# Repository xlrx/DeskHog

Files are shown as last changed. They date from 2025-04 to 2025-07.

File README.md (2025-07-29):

# DeskHog: A developer toy for sparking developer joy

Screenshot 2025-04-18 at 1 31 29 AM

## Dive in

Ready to put your kit together? [Start here.](/getting-started/start-here.md)

## What is DeskHog?
DeskHog is an open-source, 3D printed, palm-sized developer toy. 

It's a toy to tinker with, adapt, and to get curious with. We'll be folding in a library of simple example games and apps, including a pomodoro timer and versions of Pong, Rogue, Flappy Bird. You can see PRs for these in this repo now for inspiration!

We think that sounds like fun and, if you do too, then DeskHog is for you. 

## OK, but what is it?

DeskHog packs an Adafruit ESP32-S3 Reverse TFT Feather in a custom-made 3D printed case. It comes complete with a 240x135 color TFT display, a 10-hour battery life, WiFi, and a cute little LED so you can find it in the dark.

A [plug-and-play DeskHog hardware kit](https://posthog.com/merch) is coming soon (so you can get everything in one box). In the meantime, here’s what you’ll need if you want to make DeskHog yourself right now. 

- ESP32-S3 Reverse TFT Feather – [`Adafruit 5691`](https://learn.adafruit.com/esp32-s3-reverse-tft-feather) – buy: [Adafruit](https://www.adafruit.com/product/5691), [DigiKey](https://www.digikey.com/en/products/detail/adafruit-industries-llc/5691/18627502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), [Mouser](https://www.mouser.com/ProductDetail/Adafruit/5691?qs=mELouGlnn3eeALy2e3r3sw%3D%3D), [Botland (EU)](https://botland.store/arduino-compatible-boards-adafruit/22891-feather-esp32-s3-reverse-with-tft-display-wifi-module-4mb-flash-2mb-psram-compatible-with-arduino-adaf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), [The Pi Hut (UK)](https://thepihut.com/products/adafruit-esp32-s3-reverse-tft-feather-4mb-flash-2mb-psram-stemma-qt), [Electromaker](https://www.electromaker.io/shop/product/adafruit-esp32-s3-reverse-tft-feather-4mb-flash-2mb-psram-stemma-qt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), [BerryBase (EU)](https://www.berrybase.de/en/adafruit-esp32-s3-reverse-tft-feather)
- Optional: PKCell 552035 350mAh 3.7V LiPoly battery – buy: [Adafruit](https://www.adafruit.com/product/2750), [Tinytronics (EU)](https://www.tinytronics.nl/en/power/batteries/li-po/pkcell-li-po-battery-3.7v-350mah-jst-ph-lp552035), [BerryBase (EU)](https://www.berrybase.de/en/lp-552035-lithium-polymer-lipo-akku-3-7v-350mah-mit-2-pin-jst-stecker)
- 3D printed enclosure – print: [3mf file](3d-printing)

## What can DeskHog do?

DeskHog can do a couple of things by default, but the real joy lies in expanding the capabilities by adding them yourself. 

### Out of the box functionality

A couple of basic [cards](#card-stack) (screens) are included on the firmware and were built by [Danilo Campos](https://posthog.com/community/profiles/31731).

- **ProvisioningCard**: Displays a QR code to connect to the device and shows connection stats.
- **InsightCard**: Visualizes PostHog data. Still a bit of a WIP, so contributions welcome!
- **FriendCard**: Lets Max the hedgehog visit with you and provide encouragement.

### Available games and apps

We're working on adding some of the following games to an `/examples` folder which will include a selection of games and apps for you to play with. If you can't see them in the `/examples` folder it's probably because they exist as [unapproved PRs](https://github.com/PostHog/DeskHog/pulls) while we work on them. No problem, just checkout the branch!

Example games include:

- **Pog**: A Pong clone by [Leon Daly](https://posthog.com/community/profiles/30833)
- **IdleHog**: An idle clicker by [Chris McNeill](https://posthog.com/community/profiles/33534)
- **One Button Dungeon**: An idle Roguelike by [Joe Martin](https://posthog.com/community/profiles/29070)
- **Dictator or Techbro: DeskHog Edition**: A quiz game by [Chris McNeill](https://posthog.com/community/profiles/33534)
- **Notchagotchi**: A virtual pet by [Sophie Payne](https://posthog.com/community/profiles/33385)
- **Flappy Hog**: A Flappy Bird clone by [Joe Martin](https://posthog.com/community/profiles/29070)
- **Hog Speed**: A reaction game by [Chris McNeill](https://posthog.com/community/profiles/33534)
- **Pineapple Reflex**: A pizza-based game by [Sophie Payne](https://posthog.com/community/profiles/33385)
- **Three Button Dungeon**: An Ultima-like by [Joe Martin](https://posthog.com/community/profiles/29070)

Example apps include:

- **Awkwardness Avoider**: A smalltalk prompter by [Annika Schmid](https://posthog.com/community/profiles/28619)
- **Pomodoro**: A productivity timer by [Annika Schmid](https://posthog.com/community/profiles/28619)

All of the example apps were built in 24 hours at [a PostHog hackathon](https://posthog.com/handbook/company/offsites) by people who hadn't coded before at all. These example cards are a testament to [what's possible when vibe coding on DeskHog](#-vibe-coding-with-ai-agents), but some lack polish - so make sure you know [how to reset DeskHog](#buttons-and-reset-sequences). Just in case.

## Developing for DeskHog

Review [tech-details.md](tech-details.md) for info on architecture, libraries and key components used in this project.

## Troubleshooting

### No matter what I do, flashing the board doesn't change anything! wtf??

We're actually cutting the storage space in half so that over the air updates can be loaded to the unused half of storage. You can end up in a place where the board just won't boot to the correct partition.

To fix this, choose **Erase Flash and Upload** from the PlatformIO Project Tasks menu.

## 🤖 Coding with AI Agents

> DeskHog is optimized for agent development. If you've never tried coding with AI before, here's [a guide to get you started](https://posthog.com/tutorials/deskhog-claude-tutorial)!

We couldn't have built DeskHog without the help of agent development workflows, and we encourage agent-driven development with a few caveats.

LLMs often struggle with multi-threaded embedded systems. DeskHog’s firmware has strict rules for core/task roles; AI might overlook them unless you guide it.

If you're looking to [get started](https://posthog.com/tutorials/deskhog-claude-tutorial), we recommend using [Claude Code](https://www.anthropic.com/claude-code) with [Visual Studio Code](https://code.visualstudio.com/) and the [PlatformIO extension](https://platformio.org/install/ide?install=vscode). They work well together and you can build all sorts of things with natural language.

Use `tech-details.md` to give your agent broad context on the device. Still, even with that you should bear in mind the following advice:

- You should encourage AI to follow existing patterns: use`EventQueue` for cross-core messaging and update the UI only on the UI task.
- Flag any AI suggestions that touch the UI from the wrong core.
- Review and test thoroughly—watch for “LLM slop” (unused vars, odd delays) and clean it up.

Think of your AI as a speedy junior dev: brilliant but prone to mistakes. You’re the senior dev keeping it on track. With that balance, AI can boost productivity while keeping DeskHog reliable.

## Power off

If you want to turn the device off, hold ● + ▼ for two seconds. The device will enter deep sleep mode. 

To wake the device, press the reset tab on the left. 

## UI progress
- Status card: working
- WiFi provisioning card with QR Code: working
- Friend card to give you (mild) reassurance: working
- Numeric card for Big Number insights: working
- Funnel card: needs a redesign; probably should be horizontal layout instead, won't display more than three steps right now
- Line graph card: broken, not properly scaling larger data sets, probably fine if you have an insight scoped between 7-30 days
- Other insights: not yet supported

## Request for PRs

The following PRs would be interesting, and may earn you a free DeskHog kit or other merch:

- Additional insight parsing and visualizations for Insight Card
- More games and apps! We think limiting things to one available button prompts creativity
- Support for other boards and displays
- LLM slop mitigation: if you see anything obviously stupid in this code that hasn't yet been caught and cleaned up
- DX improvements around task isolation: if your experience with embedded code says there's a better way to architect this, happy to follow your lead
- Improved C++: not my preferred language, feel free to suggest idiomatic and architectural improvements
- Desk utilities, like a pomodoro timer; also constrained: center button only. Be creative!
- PlatformIO config improvements: flashing builds causes a reboot that seems unnecessary, maybe you know a better configuration

## Forks

This firmware has a simple goal: make it easy to set up a stack of screens that you can page through easily, managed by a web UI. But this is just one way to use the power of the board we chose. Feel free to steal this code, keep what helps, throw out what you don't like, and try something totally different. If you get somewhere interesting with your fork, let us know with a pull request to edit this section!

## Feedback

PRs over issues, but if you've got any trouble, feel free to open an issue. You can also contact the maintainer, danilo@posthog.com.

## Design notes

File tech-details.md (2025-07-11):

# DeskHog technical details

Microcontrollers are a pain. They've got limited memory and, for our purposes here, you've got to write C++ 🫠

But in exchange, our code can touch reality like no other kind of project. Here's what we're dealing with.

### Core and task isolation

If you've ever written mobile code, you'll feel right at home: we can only update the UI via the UI thread, otherwise the board crashes.

We've got two cores and multiple "tasks" assigned between them – task is [FreeRTOS](https://github.com/espressif/arduino-esp32/tree/master/libraries/ESP32/examples/FreeRTOS/BasicMultiThreading)-speak for threads:

**Core 0 (Protocol CPU) tasks:**

- WiFi
- Web portal server
- Insight parsing
- NeoPixel control

**Core 1 (Application CPU) tasks:**

- LVGL tick (maintains timing, animations, etc for the graphics library) 
- UI: screen drawing and input handling

We have to keep this stuff carefully isolated or we're going to crash.

### Buttons

diagram

If the board isn't responding:

- Hold **▼ (Page down/D0)**
- Press **Reset**
- Release **▼ (Page down/D0)**

The board will restart in bootloader mode, where it can be re-flashed using PlatformIO.

### Pin definitions

You don't have to guess the pin definitions. You'll find them documented here:

~/.platformio/packages/framework-arduinoespressif32/variants/adafruit_feather_esp32s3_reversetft/pins_arduino.h

## UI progress

- Status card: working
- WiFi provisioning card with QR Code: working
- Friend card to give you (mild) reassurance: working
- Numeric card for Big Number insights: working
- Funnel card: needs a redesign; probably should be horizontal layout instead, won't display more than three steps right now
- Line graph card: working decently, but could use more detail
- Other insights: not yet supported

## Important components

### Event queue

`EventQueue` is how the project manages communication between tasks and prevents coupling. Events – changes via the web UI, returned requests from the PostHog client – are dispatched out of core 0 to be received by the UI task. Any important data can be safely copied from one context into the other, preventing crashes and other drama.

### Card stack

The UI is a stack of cards. The user navigates between them using built-in buttons (the arrow keys)

`CardNavigationStack` manages the UI presentation of these cards, animating transitions.

`CardController` manages updates to the stack contents. If an insight is deleted or added via web UI, the controller processes that update reactively.

### Web UI

A basic provisioning and configuration UI is provided. You can access it via a QR code on first launch, and by the IP shown in the status screen once WiFi is configured.

Open `html/portal.html` in your browser to preview changes. The contents of `html` are inlined into a single file on each build by `htmlconvert.py`.

**Web portal budget:** Right now the portal costs about 18KB. We'll allow up to **100KB**. All portal assets must be locally available, since the portal needs to work when the device doesn't have WiFi. If you want to try adding a more complex UI framework than hand-rolled JS and HTML, you're welcome to try as long as its build system is quick and the final static output is under 100KB.

### Card system

The DeskHog uses a dynamic card system that allows users to configure which cards appear on their device through a web UI. Cards are managed by the `CardController` and can be easily extended by developers.

#### Built-in cards

`ProvisioningCard` displays a QR code to connect to the device. If WiFi is connected, it displays connection stats.

`InsightCard` visualizes PostHog data. Numeric card is working best. The rest need help.

`FriendCard` lets Max the hedgehog visit with you and provide encouragement.

#### Adding new card types

To create a new card type, you need to:

1. **Add to CardType enum** - Add your new type to the `CardType` enum in `src/ui/CardController.h`
2. **Create the card class** - Implement your card UI using LVGL
3. **Register the card type** - Add it to CardController's registration system
4. **Add configuration support** (optional) - If your card needs user input

**Example: Adding a simple "Hello World" card**

```cpp
// 1. Add to CardType enum (src/ui/CardController.h)
enum class CardType {
    INSIGHT = 0,
    FRIEND = 1,
    HELLO = 2  // Add your new type here
};

// 2. Create your card class (src/ui/HelloCard.h)
class HelloCard {
public:
    HelloCard(lv_obj_t* parent);
    lv_obj_t* getCard() const { return _card; }

private:
    lv_obj_t* _card;
};

// 3. Register in CardController::initializeCardTypes()
CardDefinition helloDef;
helloDef.type = CardType::HELLO;
helloDef.name = "Hello world";
helloDef.allowMultiple = true;
helloDef.needsConfigInput = false;
helloDef.uiDescription = "A simple greeting card";
helloDef.factory = [this](const String& configValue) -> lv_obj_t* {
    HelloCard* newCard = new HelloCard(screen);
    return newCard ? newCard->getCard() : nullptr;
};
registerCardType(helloDef);
```

**Card definition properties:**
- `type`: Unique enum value for your card type
- `name`: Display name in the web UI
- `allowMultiple`: Whether users can add multiple instances
- `needsConfigInput`: Whether the card requires configuration input
- `configInputLabel`: Label for the config input field (if needed)
- `uiDescription`: Description shown in the web UI
- `factory`: Lambda function that creates card instances

#### Web UI integration

The web UI automatically displays available card types with:
- Add buttons for cards that can be added
- Configuration inputs for cards that need them
- Status indicators showing how many instances are configured
- Drag-and-drop reordering for configured cards

No web UI changes are needed when adding new card types - everything is driven by the card registration system.

#### Creating game-like cards

Cards that need regular updates (games, animations, real-time visualizations) can use the `InputHandler::update()` method:

```cpp
// 1. Your card class should inherit from InputHandler
class FlappyHogCard : public InputHandler {
public:
    // Handle button presses (required by InputHandler)
    bool handleButtonPress(uint8_t button_index) override {
        // Return false to allow navigation, true if you handled it
        return false;
    }
    
    // Update method for game logic (called ~60 times per second)
    bool update() override {
        if (game) {
            game->loop();  // Update game state
            return true;   // Continue receiving updates
        }
        return false;      // Stop updates
    }
    
    // Required for proper cleanup
    void prepareForRemoval() override {
        // Called before LVGL object deletion
    }
};

// 2. Register the card with an InputHandler
helloDef.factory = [this](const String& configValue) -> lv_obj_t* {
    FlappyHogCard* newCard = new FlappyHogCard(screen);
    if (newCard && newCard->getCard()) {
        // Register as InputHandler to receive updates
        cardStack->registerInputHandler(newCard->getCard(), newCard);
        return newCard->getCard();
    }
    delete newCard;
    return nullptr;
};
```

The `update()` method is automatically called by the UI system when your card is active/visible. This approach:
- Works within the existing task/core architecture
- Doesn't require creating new tasks or timers
- Automatically stops updates when the card isn't visible
- Maintains proper thread safety through the existing UI queue system

### Insight parser and PostHog client

`InsightParser` ingests PostHog API responses and makes them available to the UI. `PostHogClient` constructs requests and dispatches responses.

### LVGL

This project relies on the powerful [LVGL project](https://docs.lvgl.io/9.2/intro/index.html) at [v9.2.2](https://registry.platformio.org/libraries/lvgl/lvgl?version=9.2.2) for drawing, animation and other UI tasks.

### Config manager and captive portal

`ConfigManager` handles persistent storage and retrieval of credentials and insights. `CaptivePortal` provides the web server and interacts with `ConfigManager` to read and write to persistent storage.

### PNG sprite system

The project includes a `png2c.py` script that automatically converts PNG images into LVGL-compatible C arrays. This makes it easy to add sprite-based animations and graphics to DeskHog. The script runs before each build, so your sprites are always up to date. Beware: the board has limited storage and we already use most of it. Optimize your images aggressively and use PNG files sparingly.

#### How it works

1. **Place PNG files in subdirectories** under `raw-png/`:
   ```
   raw-png/
   ├── walking/
   │   ├── frame_01.png
   │   ├── frame_02.png
   │   └── frame_03.png
   ├── idle/
   │   ├── idle_01.png
   │   └── idle_02.png
   └── attack/
       └── attack_01.png
   ```

2. **Run the conversion script**:
   ```bash
   python3 png2c.py
   ```

3. **Generated output**:
   - Individual header/source files for each sprite in `include/sprites/`
   - Filenames are preserved (e.g., `frame_01.png` → `sprite_frame_01.h/c`)
   - A master `sprites.h` and `sprites.c` containing arrays for each subdirectory

#### Using sprites in your code

```cpp
#include "sprites/sprites.h"

// Access the walking animation array
lv_obj_t* img = lv_img_create(parent);
lv_img_set_src(img, &walking_sprites[0]);  // First frame

// Animate through frames
for (int i = 0; i < walking_sprites_count; i++) {
    lv_img_set_src(img, walking_sprites[i]);
    // Add delay or use LVGL animation
}
```

#### Features

- **Automatic grouping**: Each subdirectory gets its own array (e.g., `walking_sprites[]`, `idle_sprites[]`)
- **Count variables**: Each array has a corresponding count (e.g., `walking_sprites_count`)
- **LVGL compatible**: Generates ARGB8888 format data structures that work directly with LVGL 9.x

#### Requirements

- Python 3
- Pillow and numpy (required):
  ```bash
  pip install Pillow numpy
  ```

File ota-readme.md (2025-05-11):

# DeskHog OTA Updates via GitHub Releases

This document outlines the plan for implementing Over-the-Air (OTA) firmware updates for the DeskHog project using GitHub Releases as the firmware source and integrating the process into the existing web configuration portal.

## Core Requirements for ESP32 OTA

Implementing OTA updates on the ESP32 with the Arduino framework requires several key components:

1.  **Partition Scheme:** The ESP32's flash memory needs an OTA-compatible partition table defined in `partitions.csv`. This typically includes at least two application partitions (e.g., `factory`, `ota_0`) and an `otadata` partition to manage which partition boots.
2.  **Network Connectivity:** The device must connect to Wi-Fi to check for and download updates.
3.  **Update Source:** A server to host the firmware binary (`.bin`). We will use GitHub Releases for this.
4.  **Arduino `Update` Library:** The `Update.h` library provided by the ESP32 Arduino core is used to write the downloaded firmware to the inactive partition and manage the boot process.
5.  **Update Logic:** Application code is needed to check for updates, download the binary, feed it to the `Update` library, handle errors, provide feedback, and trigger a reboot.
6.  **Firmware Binary:** The compiled `.bin` file generated by PlatformIO.
7.  **Security (Recommended):** Using HTTPS for downloads prevents tampering. Certificate management is required. Firmware signing is another potential enhancement.
8.  **Rollback:** The ESP32 bootloader provides basic rollback if a new firmware fails to boot successfully multiple times.

## Update Source: GitHub Releases Method

We will use the GitHub Releases feature of the project repository to host firmware updates:

1.  **Release Assets:** New firmware builds (`.bin` files) will be uploaded as assets to tagged releases (e.g., `v1.1.0`) on GitHub.
2.  **Checking for Updates:**
    *   The ESP32 will make an HTTPS GET request to the GitHub API endpoint: `https://api.github.com/repos/PostHog/DeskHog/releases/latest`.
    *   Requires an HTTPS client on the ESP32 and the necessary root CA certificate for `api.github.com`.
3.  **Parsing Response:**
    *   The JSON response from the API will be parsed (using `ArduinoJson`).
    *   Extract `tag_name` (version) and the `browser_download_url` for the `.bin` asset.
4.  **Version Comparison:** Compare the `tag_name` from GitHub with the currently running firmware version.
5.  **Downloading Binary:** If a newer version is found, make an HTTPS GET request to the `browser_download_url`.
6.  **Applying Update:** Stream the downloaded binary data to the Arduino `Update` library (`Update.writeStream()`). Call `Update.end()` and `ESP.restart()` on success.

## Web UI Integration (`portal.html` / `portal.js`)

The existing captive portal UI will be extended to manage OTA updates:

1.  **`portal.html` Changes:**
    *   Add a new "Firmware Update" section.
    *   Display "Current Version" (`<span id="current-version">`).
    *   Display "Available Version" (`<span id="available-version">`).
    *   Add a "Check for Updates" button (`<button id="check-update-btn">`).
    *   Add an initially hidden "Install Update" button (`<button id="install-update-btn">`).
    *   Add an optional area to display release notes (`<pre id="release-notes">`).
    *   Add a status display area for ongoing updates, including a progress bar (`<div id="update-status-container">`, `<div id="update-progress-bar">`).
    *   Add an area for displaying update errors (`<p id="update-error-message">`).

2.  **`portal.js` Changes:**
    *   **`checkFirmwareUpdate()`:** Called on page load and by the "Check" button. Fetches `/check-update`, updates the UI with current/available versions, and shows the "Install" button if an update is available.
    *   **`startFirmwareUpdate()`:** Called by the "Install" button. Confirms with the user, then POSTs to `/start-update`. On success, it initiates status polling.
    *   **`pollUpdateStatus()`:** (Optional but recommended) Called periodically after an update starts. Fetches `/update-status`, updates the progress bar and status message, and stops polling on success or error. Handles completion or errors.
    *   Modify `DOMContentLoaded` listener to call `checkFirmwareUpdate()` on initial page load.

## Backend Implementation (`CaptivePortal` / `OtaManager`)

The backend logic will reside primarily in a new class, coordinated by the existing `CaptivePortal`.

1.  **`OtaManager` (New Class):**
    *   **Responsibilities:**
        *   Encapsulate all core OTA logic.
        *   Store GitHub repository details and current firmware version.
        *   Manage HTTPS connections (including certificates) to `api.github.com`.
        *   Perform API calls (`/releases/latest`).
        *   Parse JSON responses.
        *   Download the `.bin` file via HTTPS using `WiFiClientSecure`.
        *   Interact with the Arduino `Update` library (`Update.begin`, `Update.writeStream`, `Update.end`).
        *   Track update state (idle, checking, downloading, writing, success, error) and progress.
        *   Trigger `ESP.restart()`.
    *   **Interface (Conceptual):**
        *   `struct UpdateInfo { bool updateAvailable; String currentVersion; String availableVersion; String downloadUrl; String releaseNotes; };`
        *   `UpdateInfo checkForUpdate();`
        *   `bool beginUpdate(String downloadUrl);`
        *   `struct UpdateStatus { String status; int progress; String message; };`
        *   `UpdateStatus getStatus();` // For polling

2.  **`CaptivePortal` Modifications:**
    *   **Dependencies:** Add a reference to an `OtaManager` instance (passed via constructor).
    *   **New Handler Methods:**
        *   `handleCheckUpdate()`: Calls `otaManager.checkForUpdate()`, formats the `UpdateInfo` struct into a JSON response for the UI.
        *   `handleStartUpdate()`: Retrieves the download URL (likely cached from the last check or passed from the UI), calls `otaManager.beginUpdate()`, responds with success/failure JSON.
        *   `handleUpdateStatus()`: Calls `otaManager.getStatus()`, formats the `UpdateStatus` struct into a JSON response.
    *   **`CaptivePortal::begin()`:** Register routes `/check-update` (GET), `/start-update` (POST), and `/update-status` (GET) to map to the new handler methods.

## Implementation Progress

*   **Partition Scheme (`partitions.csv`):** Updated to support OTA with two application partitions (~1.84MB each) and a smaller SPIFFS partition (256KB).
    *   _Affected file:_ `partitions.csv`
*   **`OtaManager` Class (`src/OtaManager.h`, `src/OtaManager.cpp`):
    *   Skeleton created with basic structure, structs (`UpdateInfo`, `UpdateStatus`), and method signatures.
    *   `_githubApiRootCa` updated with DigiCert Global Root G2 certificate.
    *   `checkForUpdate()` method implemented as **non-blocking** using a FreeRTOS task (`_checkUpdateTaskRunner`):
        *   Handles HTTPS GET request to GitHub API (`_performHttpsRequest`).
        *   Parses JSON response (`_parseGithubApiResponse`).
        *   Compares versions and identifies firmware asset URL.
        *   Updates internal status and makes results available via `getStatus()` and `getLastCheckResult()`.
    *   _Affected files:_ `src/OtaManager.h`, `src/OtaManager.cpp`

## Next Steps (OtaManager)

1.  Implement `OtaManager::beginUpdate()` using a FreeRTOS task to handle firmware download (HTTPS) and flashing with `Update.writeStream()`.
2.  Implement robust error handling and status reporting for the `beginUpdate` process.
3.  Implement a reliable mechanism for defining/retrieving `CURRENT_FIRMWARE_VERSION`.

This structure maintains separation of concerns, keeping web request handling (`CaptivePortal`) distinct from the OTA update mechanism (`OtaManager`).

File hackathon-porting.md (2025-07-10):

# Hackathon Card Porting Guide

This document outlines the process for porting old hackathon branches to the new card architecture in DeskHog.

## Overview

The main branch introduced a new extensible card system that allows dynamic card management through a web UI. Old branches need to be updated to use this architecture.

## Step-by-Step Porting Process

### 1. Understand the New Architecture

The new system uses:
- **CardType enum** - Defines available card types
- **CardDefinition** - Metadata for each card type
- **Factory pattern** - Lambda functions create card instances
- **InputHandler interface** - Base class for cards that handle input
- **Dynamic card management** - Cards can be added/removed via web UI

### 2. Analyze the Existing Implementation

For the Flappy Hog example:
- Original: `FlappyBirdGame` class with direct integration in main.cpp
- Had custom button handling and game loop in the LVGL task
- Direct references in CardController

### 3. Create a Card Wrapper Class

Create a wrapper that implements `InputHandler`:

```cpp
class FlappyHogCard : public InputHandler {
public:
    FlappyHogCard(lv_obj_t* parent);
    ~FlappyHogCard();
    
    lv_obj_t* getCard();
    bool handleButtonPress(uint8_t button_index) override;
    void prepareForRemoval() override;
    bool update() override;  // For game loop
    
private:
    FlappyBirdGame* game;
    lv_obj_t* cardContainer;
    bool markedForRemoval;
};
```

### 4. Update CardType Enum

In `src/config/CardConfig.h`:
- Add new card type to enum
- Update `cardTypeToString()` function
- Update `stringToCardType()` function

### 5. Register the Card Type

In `CardController::initializeCardTypes()`:
```cpp
CardDefinition flappyDef;
flappyDef.type = CardType::FLAPPY_HOG;
flappyDef.name = "Flappy Hog";
flappyDef.allowMultiple = false;
flappyDef.needsConfigInput = false;
flappyDef.uiDescription = "One button. Endless frustration. Infinite glory.";
flappyDef.factory = [this](const String& configValue) -> lv_obj_t* {
    FlappyHogCard* newCard = new FlappyHogCard(screen);
    if (newCard && newCard->getCard()) {
        CardInstance instance{newCard, newCard->getCard()};
        dynamicCards[CardType::FLAPPY_HOG].push_back(instance);
        cardStack->registerInputHandler(newCard->getCard(), newCard);
        return newCard->getCard();
    }
    delete newCard;
    return nullptr;
};
registerCardType(flappyDef);
```

### 6. Handle Game Updates

For cards needing regular updates:
1. Extend `InputHandler` interface with `virtual bool update() { return false; }`
2. Add `updateActiveCard()` to `CardNavigationStack`
3. Call it from `CardController::processUIQueue()`

This keeps the game loop encapsulated and running at the same frequency as UI updates.

### 7. Remove Old Integration Code

Clean up:
- Direct references in main.cpp
- Card-specific methods in CardController
- Manual card creation in initialization

### 8. Test the Integration

Verify:
- Card appears in web UI
- Can be added/removed dynamically
- Game functions properly
- No memory leaks or crashes
- Proper cleanup on removal

## Common Pitfalls

1. **Threading issues** - Keep all UI updates on the LVGL thread
2. **Memory management** - Use `prepareForRemoval()` to prevent double-deletion
3. **Button handling** - Return false from `handleButtonPress()` to allow navigation
4. **Update frequency** - Game updates run at UI refresh rate (~60 FPS)

## Benefits of the New System

- **Extensible** - Easy to add new card types
- **Dynamic** - Users control which cards are shown
- **Encapsulated** - No card-specific code in core systems
- **Consistent** - All cards follow the same pattern
- **Thread-safe** - Updates happen through the UI queue

## Merge Strategy

1. Commit your changes on the feature branch
2. Merge main into your branch (expect conflicts)
3. Resolve conflicts keeping the new architecture
4. Test thoroughly before creating PR

The key is to wrap the existing functionality in the new card system rather than trying to preserve the old integration approach. Do not accept changes that alter the architecture of the project as a whole.

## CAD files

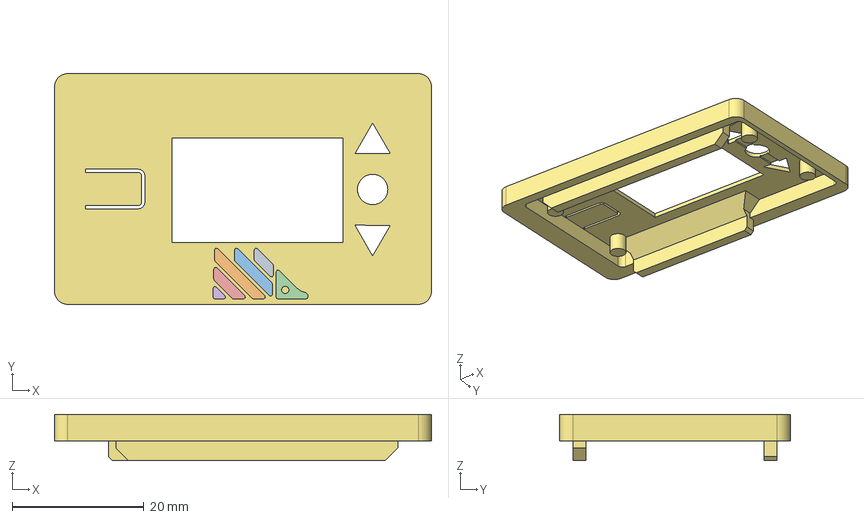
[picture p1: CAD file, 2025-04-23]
3d-printing/cad/Bezel assembly.step
57.2 x 35.0 x 7.00 mm

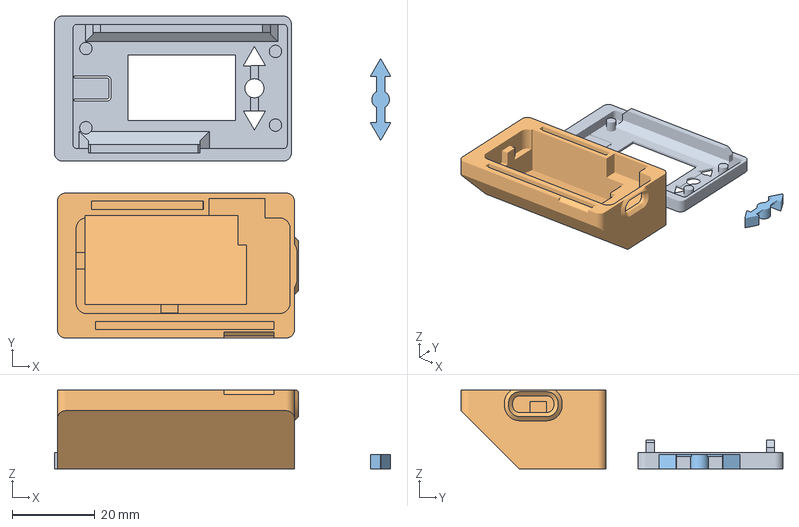
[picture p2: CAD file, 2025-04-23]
3d-printing/DeskHog-all_parts.3mf
81.1 x 77.7 x 19.0 mm
Bezel assembly
Enclosure*
Keypad

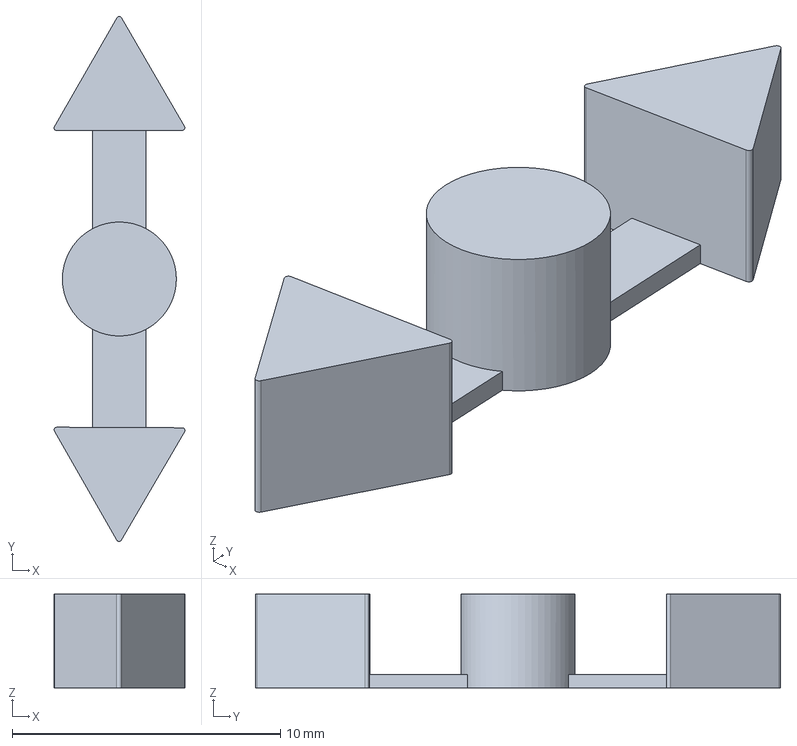
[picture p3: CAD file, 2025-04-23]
3d-printing/cad/Keypad.step
4.88 x 19.6 x 3.50 mm

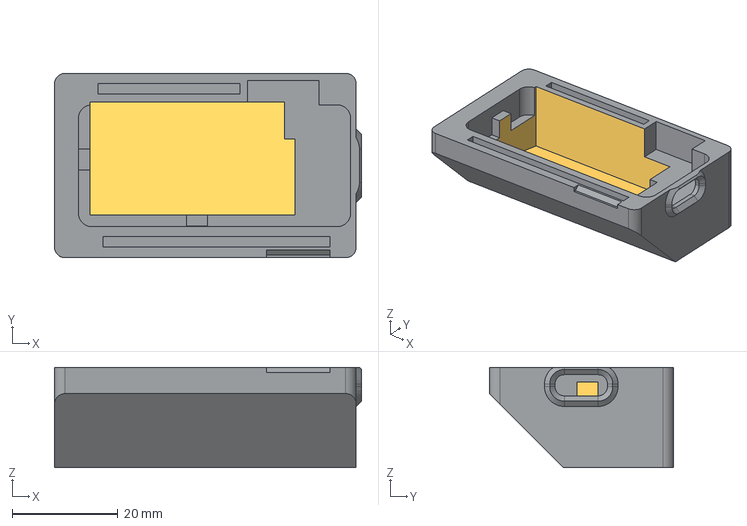
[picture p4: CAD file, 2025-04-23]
3d-printing/cad/Enclosure.step
58.2 x 35.0 x 19.0 mm

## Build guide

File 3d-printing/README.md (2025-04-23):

# Printing

`DeskHog-all_parts.3mf` contains everything you need to print your own DeskHog. All parts are at their intended printing orientations.

DeskHog prints have been tested with PETG on Bambu printers. For best results, stick with translucent PETG. The tool-free, friction-fit assembly requires dialed-in dimensional accuracy (Bambu worked fine out of the box, others may require some tuning). If the pieces are a little snug, a modeling file or sandpaper across the tabs on the bezel can probably get you on your way.

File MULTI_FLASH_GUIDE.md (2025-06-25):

# Multi-Board Flash Utility for DeskHog

This utility automatically detects and flashes DeskHog firmware to multiple ESP32-S3 boards as they are connected.

## Features

- Automatically detects new ESP32-S3 Feather boards when plugged in
- Maintains an in-memory list of already-flashed boards to prevent re-flashing
- Supports parallel flashing of multiple boards
- Real-time monitoring of board connections/disconnections
- Live progress display with visual progress bars
- Status tracking for each board (building, flashing, verifying, etc.)
- Verbose mode for debugging

## Requirements

- Python 3.6+
- PlatformIO CLI (`pip install platformio`)
- pyserial (`pip install pyserial`)
- USB drivers for ESP32-S3

## Usage

### Basic Usage

From the DeskHog project root directory:

```bash
python multi_flash.py
```

Or if you made it executable:

```bash
./multi_flash.py
```

### Command Line Options

- `-v, --verbose`: Show detailed flashing output
- `-f, --firmware <path>`: Use a specific firmware file instead of building
- `-r, --reset`: Clear the list of flashed boards and exit

### Examples

1. **Basic monitoring and flashing:**
   ```bash
   python multi_flash.py
   ```

2. **Verbose mode (see detailed upload progress):**
   ```bash
   python multi_flash.py -v
   ```

3. **Flash a specific firmware file:**
   ```bash
   python multi_flash.py -f .pio/build/adafruit_feather_esp32s3_reversetft/firmware.bin
   ```

4. **Reset the flashed board memory:**
   ```bash
   python multi_flash.py -r
   ```

## How It Works

1. The script continuously scans for connected USB devices
2. When it detects an ESP32-S3 board (by VID/PID or description), it checks if it's already been flashed
3. New boards are automatically flashed using PlatformIO's upload command
4. Successfully flashed boards are remembered to prevent re-flashing
5. The script handles multiple boards simultaneously using threading
6. A real-time display shows:
   - Active flashing operations with progress bars
   - Current status (building, connecting, writing, verifying)
   - Completed boards with success/failure indicators
   - Total count of flashed boards

## Board Detection

The script identifies ESP32-S3 boards by:
- USB Vendor ID: 0x303A (Espressif) or 0x239A (Adafruit)
- USB Product ID: Various ESP32-S3 identifiers
- Device description containing "ESP32", "ESP32-S3", "Adafruit", or "Feather"

## Troubleshooting

### Board not detected
- Make sure the board is in normal mode (not bootloader mode)
- Check USB cable and connection
- Try verbose mode to see what devices are being detected

### Flashing fails
- The board might need to be put in bootloader mode manually (hold D0 while pressing Reset)
- Check that PlatformIO is properly installed
- Ensure you're running from the DeskHog project root directory

### Board keeps getting re-flashed
- This might happen if the board doesn't have a unique serial number
- Try disconnecting and reconnecting the board
- Use the reset option (`-r`) to clear the memory if needed

## Tips

- Keep the script running while connecting multiple boards
- Boards can be connected one at a time or multiple at once
- The display automatically refreshes to show real-time progress
- Progress bars show the current stage of flashing (0-100%)
- Status indicators:
  - 🔄 = Currently flashing
  - ✅ = Successfully flashed
  - ❌ = Failed to flash
  - ⚠️  = Disconnected during flash
- Press Ctrl+C to stop monitoring

## Display Example

```
================================================================================
DeskHog Multi-Board Flash Monitor
================================================================================
Time: 14:32:15 | Press Ctrl+C to stop
--------------------------------------------------------------------------------

📊 Board Status (2 flashed, 1 active):

  🔄 /dev/cu.usbmodem14201 [████████████████░░░░░░░░░░░░░] 54% - Writing firmware
  ✅ 303A:1001:ABCD1234                                     - ✓ Successfully flashed
  ✅ 239A:811C:XYZ789                                       - ✓ Successfully flashed

--------------------------------------------------------------------------------
💡 Tip: Boards are automatically detected and flashed when plugged in
```

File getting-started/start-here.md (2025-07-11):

Welcome to the adventure of programmable hardware.

Let’s get you going.

# What's going on?

DeskHog is a palm-sized computer that connects to WiFi. What happens after that is something you can decide by writing new code for it. We've done our best to take care of the boring stuff for you:

- WiFi setup
- Drawing to the screen
- Building an interface so you can navigate between different cards
- A web portal to change settings

From here you can make simple games, connect to web services, or come up with your own adventure.

# Assembly

Whether you received DeskHog as a kit or printed a case yourself, assembly is pretty straightforward. The battery wire will take a moment of finesse.

You’re going to make a sandwich, in this order:

- Base (largest plastic piece)
- Battery
- Board
- Buttons
- Top face (with the PostHog logo)

Stack those pieces together and you’re done.

## Finessing the battery

The battery cable can be a little annoying. Here are tips:

Your battery includes a small piece of tape. Reuse that tape to *bind the battery wires together*. It works best to place the tape at the midpoint of the wires.

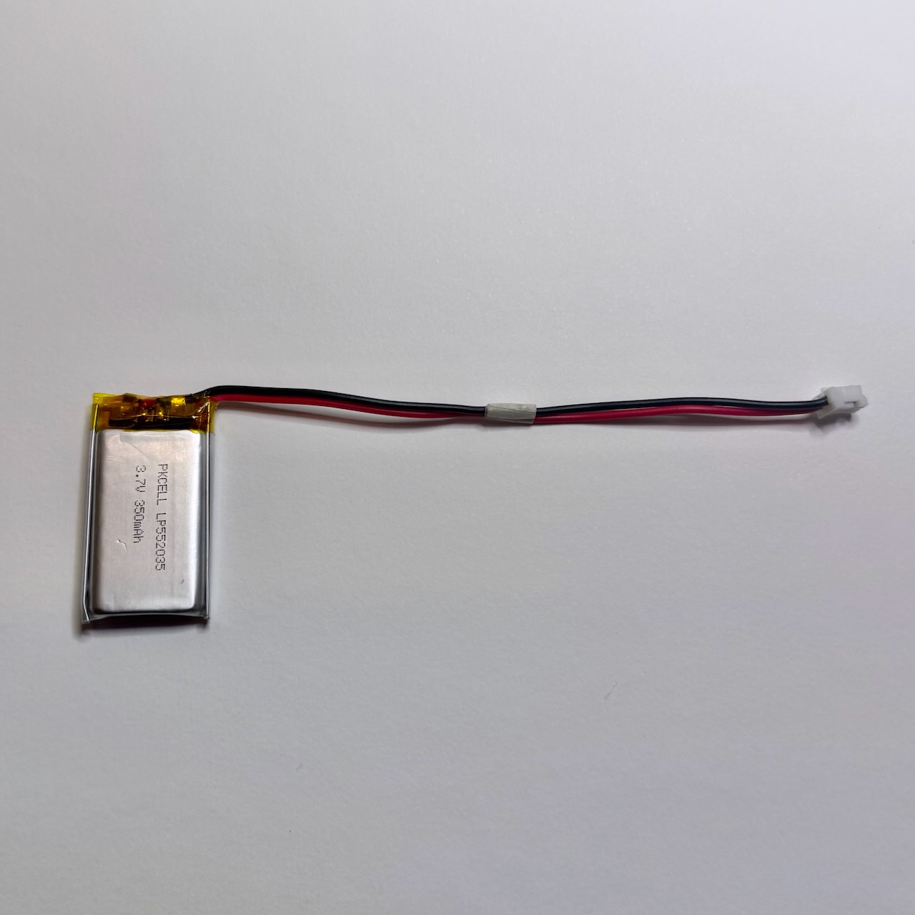
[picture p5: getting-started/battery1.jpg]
Battery wire taping


Once secured, gently but firmly bend the wires to form a **V** right before the tape, on the side of the battery.

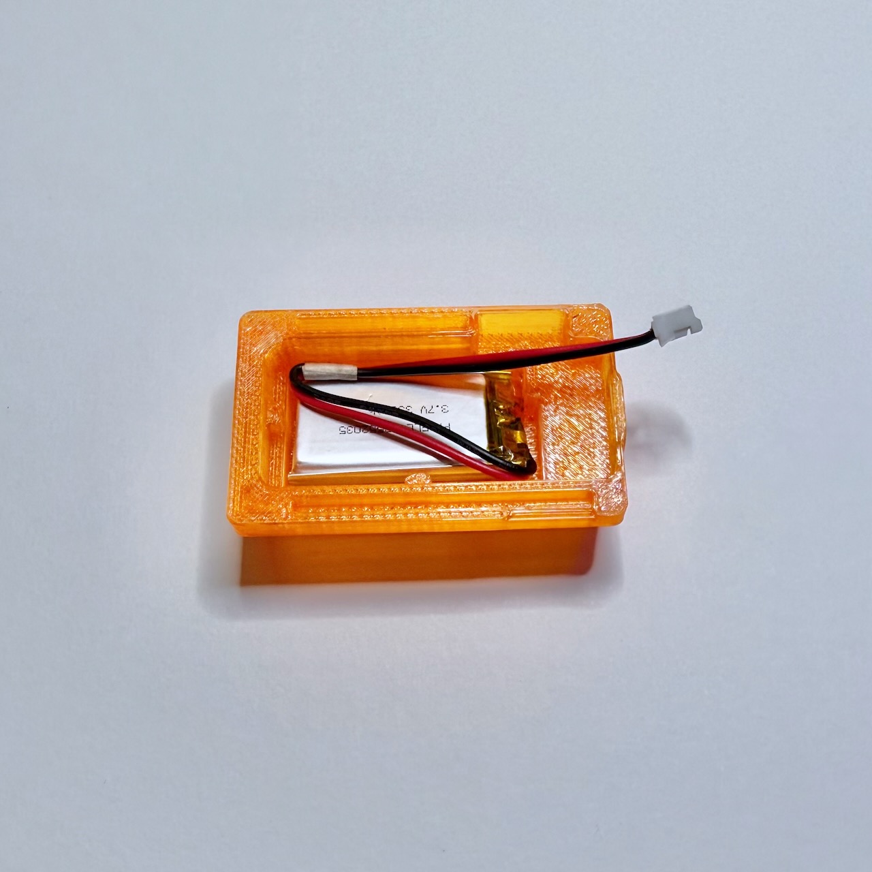
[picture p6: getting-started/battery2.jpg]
Battery wire bending


Align the spot on the battery where the wires come out with the small notch cut into the battery well.

From here, attach the battery to the board and attempt to lay the board into its space.

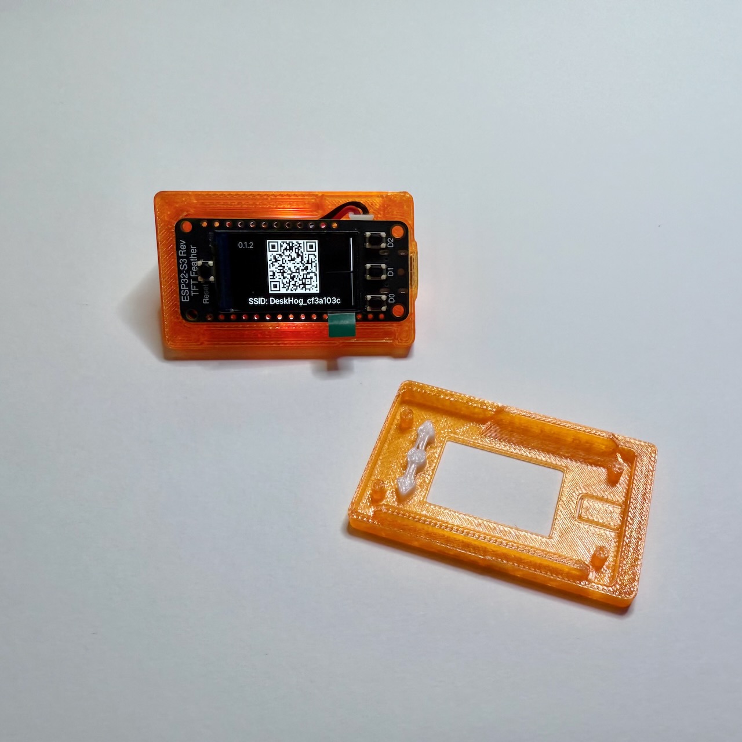
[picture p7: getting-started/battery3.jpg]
Battery placement


# Dive in

Once assembled, you can scan DeskHog’s QR code to access its configuration portal. You can also connect directly from any computer by choosing the WiFi SSID shown under the QR code from your machine’s WiFi menu.

After you give DeskHog WiFi credentials, you can access the portal again anytime by visiting its IP in your web browser. DeskHog’s status card, always shown at the top of the stack, will show its IP. You should also update to the latest firmware via the portal.

The project includes a `Hello, world!` card in `src/ui/examples`. You can start noodling with it immediately. To add or remove the card, visit DeskHog’s configuration portal.

Ready to go deeper? Check out [this tutorial](https://posthog.com/tutorials/deskhog-claude-tutorial) on how you can use agent coding products like Claude to build more interesting things on DeskHog's software. Whether you're a robot or a human, the [tech-details.md](/tech-details.md) file will help you get your bearings.

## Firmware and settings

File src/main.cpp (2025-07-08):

/**
 * DeskHog - PostHog Analytics Display
 * ===================================
 * 
 * An ESP32-S3-based project that displays PostHog analytics insights on a 240x135 TFT screen.
 * Built for the Adafruit ESP32-S3 Reverse TFT Feather, this project provides a compact, desk-friendly way to monitor your PostHog analytics in real-time.
 * 
 * Components:
 * - Hardware: ESP32-S3 with integrated 240x135 TFT display
 * - UI: LVGL-based card interface for displaying insights
 * - Network: WiFi connectivity with captive portal for configuration
 * 
 * Development note:
 * Keep this main.cpp file lean, tidy and simple. Do not leak implementation details into the main file.
 * Keep main.cpp focused on setup and task creation. Encapsulate and isolate components into their own files.
 */

#include <Arduino.h>
#include <lvgl.h>
#include <Adafruit_ST7789.h>
#include "ConfigManager.h"
#include "hardware/WifiInterface.h"
#include "hardware/NeoPixelController.h"
#include "ui/CaptivePortal.h"
#include "ui/ProvisioningCard.h"
#include "hardware/DisplayInterface.h"
#include "ui/CardNavigationStack.h"
#include "ui/InsightCard.h"
#include "hardware/Input.h"
#include "posthog/PostHogClient.h"
#include "Style.h"
#include "esp_heap_caps.h" // For PSRAM management
#include "ui/CardController.h"
#include "EventQueue.h"
#include "esp_partition.h" // Include for partition functions
#include "OtaManager.h"
#include <esp_sleep.h> // Added for deep sleep functionality
#include <esp_pm.h> // Added for power management

// Display dimensions
#define SCREEN_WIDTH 240
#define SCREEN_HEIGHT 135

// LVGL display buffer size
#define LVGL_BUFFER_ROWS 135  // Full screen height

// Button configuration
#define NUM_BUTTONS 3
const uint8_t BUTTON_PINS[NUM_BUTTONS] = {
    Input::BUTTON_DOWN,    // BOOT button
    Input::BUTTON_CENTER,  // Center button
    Input::BUTTON_UP       // Up button
};

// Define the global buttons array
Bounce2::Button buttons[NUM_BUTTONS];

// Global objects
DisplayInterface* displayInterface;
ConfigManager* configManager;
WiFiInterface* wifiInterface;
CaptivePortal* captivePortal;
CardController* cardController; // Replace individual card objects with controller
PostHogClient* posthogClient;
EventQueue* eventQueue; // Add global EventQueue
NeoPixelController* neoPixelController;  // Renamed from neoPixelManager
OtaManager* otaManager;

// Task handles
TaskHandle_t wifiTask;
TaskHandle_t portalTask;
TaskHandle_t insightTask;
TaskHandle_t neoPixelTask;

// WiFi connection timeout in milliseconds
#define WIFI_TIMEOUT 30000

// WiFi task that handles WiFi operations
void wifiTaskFunction(void* parameter) {
    while (1) {
        // Process WiFi events
        wifiInterface->process();
        
        // Delay to prevent hogging CPU
        vTaskDelay(pdMS_TO_TICKS(10));
    }
}

// Captive portal task that handles web server requests
void portalTaskFunction(void* parameter) {
    while (1) {
        captivePortal->processAsyncOperations(); // Process pending portal actions
        // Delay to prevent hogging CPU
        vTaskDelay(pdMS_TO_TICKS(100)); // Check for operations every 100ms
    }
}

// Insight processing task
void insightTaskFunction(void* parameter) {
    while (1) {
        posthogClient->process();  // Use the global instance
        vTaskDelay(pdMS_TO_TICKS(100));  // Check every 100ms
    }
}

// LVGL handler task that includes button polling - added here to consolidate UI operations
void lvglHandlerTask(void* parameter) {
    TickType_t lastButtonCheck = xTaskGetTickCount();
    const TickType_t buttonCheckInterval = pdMS_TO_TICKS(50); // Check buttons every 50ms
    
    static unsigned long powerOffPressStartTime = 0;
    // static bool upPressedState = false; // Unused
    // static bool downPressedState = false; // Unused

    while (1) {
        // Handle LVGL tasks
        displayInterface->handleLVGLTasks();

        cardController->processUIQueue();
        
        // Poll buttons at regular intervals
        TickType_t currentTime = xTaskGetTickCount();
        if ((currentTime - lastButtonCheck) >= buttonCheckInterval) {
            lastButtonCheck = currentTime;
            
            // Update all buttons first
            for (int i = 0; i < NUM_BUTTONS; i++) {
                buttons[i].update();
            }

            // Get current state of UP and DOWN buttons
            // BUTTON_UP is pressed when HIGH (INPUT_PULLDOWN)
            // BUTTON_DOWN is pressed when LOW (INPUT_PULLUP)
            bool centerButtonHeld = (buttons[Input::BUTTON_CENTER].read() == HIGH);
            bool downButtonHeld = (buttons[Input::BUTTON_DOWN].read() == LOW);

            if (centerButtonHeld && downButtonHeld) {
                if (powerOffPressStartTime == 0) { // Both pressed, start timer
                    powerOffPressStartTime = millis();
                } else {
                    if (millis() - powerOffPressStartTime >= 2000) { // Held for 2 seconds
                        Serial.println("Simultaneous CENTER and DOWN hold for 2s detected. Entering deep sleep.");
                        // Optional: Turn off display backlight or other peripherals before sleep
                        // displayInterface->setBacklight(0); // Example if such a function exists
                        esp_deep_sleep_start();
                    }
                }
            } else {
                // If either button is released or not simultaneously pressed, reset the timer
                powerOffPressStartTime = 0;

                // Process individual button presses if power-off sequence is not active or completed.
                // Check .pressed() for single press actions (triggers on state change).
                // This ensures that navigation still works if the power-off combo isn't fully executed.
                if (buttons[Input::BUTTON_UP].pressed()) {
                    // Ensure this doesn't trigger if it was part of the combo that just got released
                    // However, .pressed() fires on the transition, so if it was held and released, 
                    // it won't fire again here unless pressed again separately.
                    cardController->getCardStack()->handleButtonPress(Input::BUTTON_UP);
                }
                if (buttons[Input::BUTTON_DOWN].pressed()) {
                    cardController->getCardStack()->handleButtonPress(Input::BUTTON_DOWN);
                }
                if (buttons[Input::BUTTON_CENTER].pressed()) {
                    cardController->getCardStack()->handleButtonPress(Input::BUTTON_CENTER);
                }
            }
        }
        
        vTaskDelay(pdMS_TO_TICKS(5));
    }
}

// NeoPixel update task
void neoPixelTaskFunction(void* parameter) {
    while (1) {
        neoPixelController->update();
        vTaskDelay(pdMS_TO_TICKS(5));  // Small delay to prevent task starvation
    }
}

void setup() {
    Serial.begin(115200); // Keep Serial.begin() as it initializes the port
    delay(100);  // Give serial port time to initialize
    Serial.println("Starting up...");

    if (psramInit()) {
        Serial.println("PSRAM initialized successfully");
        Serial.printf("Total PSRAM: %d bytes\n", ESP.getPsramSize());
        Serial.printf("Free PSRAM: %d bytes\n", ESP.getFreePsram());
        
        // Set memory allocation preference to PSRAM
        heap_caps_malloc_extmem_enable(4096);
    } else {
        Serial.println("PSRAM initialization failed!");
        while(1); // Stop here if PSRAM init fails
    }

    // Configure power management for automatic light sleep
    esp_pm_config_t pm_config = {
        .max_freq_mhz = 240,  // Maximum CPU frequency
        .min_freq_mhz = 10,   // Minimum CPU frequency when idle
        .light_sleep_enable = true  // Enable automatic light sleep
    };
    
    esp_err_t pm_result = esp_pm_configure(&pm_config);
    if (pm_result == ESP_OK) {
        Serial.println("Power management configured: Light sleep enabled");
    } else {
        Serial.printf("Failed to configure power management: %s\n", esp_err_to_name(pm_result));
    }
    
    // Add Partition Logging Here
    Serial.println("--- Partition Table Info ---");
    esp_partition_iterator_t it = esp_partition_find(ESP_PARTITION_TYPE_ANY, ESP_PARTITION_SUBTYPE_ANY, NULL);
    if (it == NULL) {
        Serial.println("Could not find partitions!");
    } else {
        while (it != NULL) {
            const esp_partition_t *p = esp_partition_get(it);
            if (p == NULL) {
                // Added null check for safety, might occur if iterator is exhausted
                it = esp_partition_next(it); // Make sure to advance iterator even if partition is null
                continue;
            }
            Serial.printf("  Label: %-10s Type: 0x%02x Subtype: 0x%02x Offset: 0x%08x Size: 0x%08x (%d KB)\n",
                          p->label, p->type, p->subtype, p->address, p->size, p->size / 1024);
            it = esp_partition_next(it);
        }
        esp_partition_iterator_release(it); // Release the iterator!
    }
    Serial.println("--------------------------");

    // UI queue will be initialized by CardController


    SystemController::begin();
    
    // Initialize styles and fonts
    Style::init();
    
    // Initialize event queue first
    eventQueue = new EventQueue(20); // Create queue with capacity for 20 events
    eventQueue->begin(); // Start event processing
    
    // Initialize NeoPixel controller
    neoPixelController = new NeoPixelController();
    neoPixelController->begin();
    
    // Initialize config manager with event queue
    configManager = new ConfigManager(*eventQueue);
    configManager->begin();
    
    // Initialize PostHog client with event queue
    posthogClient = new PostHogClient(*configManager, *eventQueue);
    
    // Initialize display manager
    displayInterface = new DisplayInterface(
        SCREEN_WIDTH, SCREEN_HEIGHT, LVGL_BUFFER_ROWS, 
        TFT_CS, TFT_DC, TFT_RST, TFT_BACKLITE
    );
    displayInterface->begin();
    
    // Initialize WiFi manager with event queue
    wifiInterface = new WiFiInterface(*configManager, *eventQueue);
    wifiInterface->begin();
    
    // Initialize buttons
    Input::configureButtons();
    
    // Configure GPIO wakeup for buttons to wake from light sleep
    gpio_wakeup_enable((gpio_num_t)Input::BUTTON_UP, GPIO_INTR_HIGH_LEVEL);
    gpio_wakeup_enable((gpio_num_t)Input::BUTTON_DOWN, GPIO_INTR_LOW_LEVEL);  
    gpio_wakeup_enable((gpio_num_t)Input::BUTTON_CENTER, GPIO_INTR_HIGH_LEVEL);
    esp_sleep_enable_gpio_wakeup();
    Serial.println("GPIO wakeup configured for buttons");
    
    // Create and initialize card controller
    cardController = new CardController(
        lv_scr_act(),
        SCREEN_WIDTH,
        SCREEN_HEIGHT,
        *configManager,
        *wifiInterface,
        *posthogClient,
        *eventQueue
    );
    
    // Initialize with display interface directly
    cardController->initialize(displayInterface);
    
    // Initialize OtaManager
    otaManager = new OtaManager(CURRENT_FIRMWARE_VERSION, "PostHog", "DeskHog");
    
    // Initialize captive portal
    captivePortal = new CaptivePortal(*configManager, *wifiInterface, *eventQueue, *otaManager, *cardController);
    captivePortal->begin();
    
    // Create task for WiFi operations
    xTaskCreatePinnedToCore(
        wifiTaskFunction,
        "wifiTask",
        4096,
        NULL,
        1,
        &wifiTask,
        0
    );
    
    // Create task for captive portal
    xTaskCreatePinnedToCore(
        portalTaskFunction,
        "portalTask",
        8192,
        NULL,
        1,
        &portalTask,
        1
    );
    
    // Create task for insight processing
    xTaskCreatePinnedToCore(
        insightTaskFunction,
        "insightTask",
        8192,
        NULL,
        1,
        &insightTask,
        0
    );
    
    // Create LVGL tick task
    xTaskCreatePinnedToCore(
        DisplayInterface::tickTask,
        "lv_tick_task",
        2048,
        NULL,
        1,
        NULL,
        1
    );
    
    // Create LVGL handler task (now includes button polling)
    xTaskCreatePinnedToCore(
        lvglHandlerTask,
        "lvglTask",
        8192,
        NULL,
        2,
        NULL,
        1
    );
    
    // Create NeoPixel task
    xTaskCreatePinnedToCore(
        neoPixelTaskFunction,
        "neoPixelTask",
        2048,
        NULL,
        1,
        &neoPixelTask,
        0
    );
    
    // Check if we have WiFi credentials and publish the appropriate event
    configManager->checkWiFiCredentialsAndPublish();

    SystemController::setSystemState(SystemState::SYS_READY);
}

void loop() {
    // Empty - tasks handle everything
    vTaskDelete(NULL);
    
}

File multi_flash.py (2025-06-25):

#!/usr/bin/env python3
"""
Multi-board flash utility for DeskHog
Automatically detects and flashes new ESP32-S3 boards when connected
"""

import serial.tools.list_ports
import subprocess
import time
import sys
import threading
import os
from datetime import datetime
from typing import Set, Dict, Optional
import argparse
import re
from collections import defaultdict

class BoardFlasher:
    def __init__(self, firmware_path: Optional[str] = None, verbose: bool = False):
        self.flashed_boards: Set[str] = set()
        self.running = True
        self.verbose = verbose
        self.firmware_path = firmware_path
        self.lock = threading.Lock()
        
        # Board status tracking
        self.board_status = {}  # board_id -> status string
        self.board_progress = {}  # board_id -> progress percentage
        self.active_flashing = {}  # board_id -> port device
        self.status_lock = threading.Lock()
        
        # ESP32-S3 vendor/product IDs
        self.target_vids = [0x303A]  # Espressif
        self.target_pids = [0x1001]  # ESP32-S3 USB JTAG/serial
        
        # Adafruit Feather ESP32-S3 can also appear as
        self.alt_vids = [0x239A]  # Adafruit
        self.alt_pids = [0x811C, 0x811D]  # Various Adafruit ESP32-S3 boards
        
    def log(self, message: str):
        timestamp = datetime.now().strftime("%H:%M:%S")
        print(f"[{timestamp}] {message}")
        
    def is_target_board(self, port) -> bool:
        """Check if the connected device is our target ESP32-S3 board"""
        if port.vid in self.target_vids and port.pid in self.target_pids:
            return True
        if port.vid in self.alt_vids and port.pid in self.alt_pids:
            return True
        
        # Also check description/manufacturer strings
        desc_lower = (port.description or "").lower()
        manuf_lower = (port.manufacturer or "").lower()
        
        esp32_keywords = ["esp32", "esp32-s3", "esp32s3"]
        adafruit_keywords = ["adafruit", "feather"]
        
        has_esp32 = any(kw in desc_lower or kw in manuf_lower for kw in esp32_keywords)
        has_adafruit = any(kw in desc_lower or kw in manuf_lower for kw in adafruit_keywords)
        
        return has_esp32 or has_adafruit
        
    def get_board_id(self, port) -> str:
        """Generate unique ID for a board based on serial number or port info"""
        if port.serial_number:
            return f"{port.vid:04X}:{port.pid:04X}:{port.serial_number}"
        else:
            # Fallback to location/hardware ID if no serial number
            return f"{port.vid:04X}:{port.pid:04X}:{port.device}"
            
    def scan_ports(self) -> Dict[str, any]:
        """Scan for connected ESP32-S3 boards"""
        boards = {}
        try:
            ports = serial.tools.list_ports.comports()
            for port in ports:
                if self.is_target_board(port):
                    board_id = self.get_board_id(port)
                    boards[board_id] = port
                    if self.verbose:
                        self.log(f"Found board: {port.device} - {port.description}")
        except Exception as e:
            self.log(f"Error scanning ports: {e}")
        return boards
        
    def update_status(self, board_id: str, status: str, progress: Optional[float] = None):
        """Update board status and progress"""
        with self.status_lock:
            self.board_status[board_id] = status
            if progress is not None:
                self.board_progress[board_id] = progress
                
    def parse_progress(self, line: str) -> Optional[float]:
        """Parse progress from esptool output"""
        # Look for percentage patterns like "Writing at 0x00010000... (6%)"
        match = re.search(r'\((\d+)%\)', line)
        if match:
            return float(match.group(1))
        return None
        
    def flash_board(self, port_device: str, board_id: str) -> bool:
        """Flash firmware to a specific board"""
        self.update_status(board_id, "Preparing to flash", 0)
        
        try:
            # Build the PlatformIO upload command
            cmd = ["pio", "run", "-t", "upload", "--upload-port", port_device]
            
            if self.firmware_path:
                # If specific firmware provided, use it
                cmd.extend(["--upload-command", f"esptool.py write_flash 0x0 {self.firmware_path}"])
            
            # Run the upload command
            process = subprocess.Popen(
                cmd,
                stdout=subprocess.PIPE,
                stderr=subprocess.STDOUT,
                universal_newlines=True,
                bufsize=1
            )
            
            self.update_status(board_id, "Building firmware", 5)
            
            # Stream output in real-time
            for line in iter(process.stdout.readline, ''):
                if line:
                    line = line.rstrip()
                    if self.verbose:
                        print(f"  {line}")
                    
                    # Update status based on output
                    if "Building" in line:
                        self.update_status(board_id, "Building firmware", 10)
                    elif "Linking" in line:
                        self.update_status(board_id, "Linking firmware", 20)
                    elif "Retrieving maximum program size" in line:
                        self.update_status(board_id, "Checking firmware size", 25)
                    elif "Configuring upload protocol" in line:
                        self.update_status(board_id, "Configuring upload", 30)
                    elif "Connecting" in line:
                        self.update_status(board_id, "Connecting to board", 35)
                    elif "Chip is" in line:
                        self.update_status(board_id, "Connected to chip", 40)
                    elif "Erasing flash" in line:
                        self.update_status(board_id, "Erasing flash", 45)
                    elif "Writing at" in line:
                        progress = self.parse_progress(line)
                        if progress:
                            # Map 0-100% of writing to 50-95% of total progress
                            total_progress = 50 + (progress * 0.45)
                            self.update_status(board_id, f"Writing firmware", total_progress)
                    elif "Verifying" in line:
                        self.update_status(board_id, "Verifying firmware", 96)
                    elif "Leaving" in line or "Hard resetting" in line:
                        self.update_status(board_id, "Completing", 99)
                    
            process.wait()
            
            if process.returncode == 0:
                self.update_status(board_id, "✓ Successfully flashed", 100)
                return True
            else:
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

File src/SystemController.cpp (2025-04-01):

#include "SystemController.h"

// Initialize static member
SystemController* SystemController::instance = nullptr;

// Private constructor
SystemController::SystemController() : state{
    WifiState::DISCONNECTED,  // Initial WiFi state
    ApiState::API_NONE,
    AuthState::AUTH_NONE,
    SystemState::SYS_BOOTING
} {}

void SystemController::begin() {
    // Register for WiFi state changes
    WiFiInterface::onStateChange(onWiFiStateChange);
    SystemController::setSystemState(SystemState::SYS_BOOTING);
}

// WiFi event handler
void SystemController::onWiFiStateChange(WiFiState new_state) {
    if (getInstance()->state.wifi_state != new_state) {
        getInstance()->state.wifi_state = new_state;
        getInstance()->notify_state_change();
    }
}

// Singleton access method
SystemController* SystemController::getInstance() {
    if (instance == nullptr) {
        instance = new SystemController();
    }
    return instance;
}

// State accessors
WifiState SystemController::getWifiState() {
    return getInstance()->state.wifi_state;
}

ApiState SystemController::getApiState() {
    return getInstance()->state.api_state;
}

AuthState SystemController::getAuthState() {
    return getInstance()->state.auth_state;
}

SystemState SystemController::getSystemState() {
    return getInstance()->state.sys_state;
}

ControllerState SystemController::getFullState() {
    return getInstance()->state;
}

// State setters
void SystemController::setApiState(ApiState new_state) {
    if (getInstance()->state.api_state != new_state) {
        getInstance()->state.api_state = new_state;
        getInstance()->notify_state_change();
    }
}

void SystemController::setAuthState(AuthState new_state) {
    if (getInstance()->state.auth_state != new_state) {
        getInstance()->state.auth_state = new_state;
        getInstance()->notify_state_change();
    }
}

void SystemController::setSystemState(SystemState new_state) {
    if (getInstance()->state.sys_state != new_state) {
        getInstance()->state.sys_state = new_state;
        getInstance()->notify_state_change();
    }
}

// Notify state changes and log
void SystemController::notify_state_change() {
    auto* controller = getInstance();
    
    // Log state changes
    Serial.println("State change:");
    Serial.print("  WiFi: ");
    switch (controller->state.wifi_state) {
        case WifiState::DISCONNECTED: Serial.println("DISCONNECTED"); break;
        case WifiState::CONNECTING: Serial.println("CONNECTING"); break;
        case WifiState::CONNECTED: Serial.println("CONNECTED"); break;
        case WifiState::AP_MODE: Serial.println("AP_MODE"); break;
    }
    
    Serial.print("  API: ");
    switch (controller->state.api_state) {
        case ApiState::API_NONE: Serial.println("NONE"); break;
        case ApiState::API_AWAITING_CONFIG: Serial.println("AWAITING_CONFIG"); break;
        case ApiState::API_CONFIG_INVALID: Serial.println("CONFIG_INVALID"); break;
        case ApiState::API_CONFIGURED: Serial.println("CONFIGURED"); break;
    }
    
    Serial.print("  Auth: ");
    switch (controller->state.auth_state) {
        case AuthState::AUTH_NONE: Serial.println("NONE"); break;
        case AuthState::AUTH_AWAITING_LOGIN: Serial.println("AWAITING_LOGIN"); break;
        case AuthState::AUTH_CONFIRMED: Serial.println("CONFIRMED"); break;
    }
    
    Serial.print("  System: ");
    switch (controller->state.sys_state) {
        case SystemState::SYS_BOOTING: Serial.println("BOOTING"); break;
        case SystemState::SYS_READY: Serial.println("READY"); break;
        case SystemState::SYS_IDLE: Serial.println("IDLE"); break;
        case SystemState::SYS_INSIGHTS_CHANGED: Serial.println("INSIGHTS_CHANGED"); break;
    }
    
    // Notify all registered callbacks
    for (const auto& callback : controller->state_change_callbacks) {
        callback(controller->state);
    }
}

// Callback management
void SystemController::onStateChange(StateChangeCallback callback) {
    getInstance()->state_change_callbacks.push_back(callback);
    // Immediately call the callback with the current state
    callback(getInstance()->state);
}

void SystemController::removeAllCallbacks() {
    getInstance()->state_change_callbacks.clear();
}

// Utility methods
bool SystemController::isSystemFullyReady() {
    return getWifiState() == WifiState::CONNECTED &&
           getApiState() == ApiState::API_CONFIGURED &&
           (getSystemState() == SystemState::SYS_READY || 
            getSystemState() == SystemState::SYS_IDLE ||
            getSystemState() == SystemState::SYS_INSIGHTS_CHANGED);
}

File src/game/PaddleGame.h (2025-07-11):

#ifndef PADDLE_GAME_H
#define PADDLE_GAME_H

#include <cstdint> // For int16_t etc.

// A simple struct for 2D coordinates
struct Coordinates {
    int16_t x;
    int16_t y;
};

class PaddleGame {
public:
    PaddleGame(int16_t play_area_width, int16_t play_area_height);
    ~PaddleGame();

    void update();
    void reset();

    // Placeholder for game states
    enum class GameState {
        StartScreen,
        Playing,
        Paused,
        ServeDelay, // New state for delay before serve
        GameOver
    };

    // Enum to indicate win state when game is over
    enum PlayerWinState {
        PLAYER_WON,
        AI_WON,
        GAME_NOT_OVER // Should not happen if getState() is GameOver, but good for completeness
    };

    GameState getState() const;
    PlayerWinState getPlayerWinState() const;
    void setState(GameState state);

    // Placeholder for paddle/ball positions and scores
    // These will be fleshed out later
    int getPlayerScore() const;
    int getAiScore() const;

    Coordinates getPlayerPaddleCoordinates() const;
    Coordinates getAiPaddleCoordinates() const;
    Coordinates getBallCoordinates() const;

    // Methods to control player paddle based on input
    void movePlayerPaddle(bool move_up, bool start_moving);

    // Constants for game elements, used for physics and boundaries
    // These should ideally match the UI rendering dimensions from PaddleCard.h
    static constexpr int16_t PADDLE_WIDTH = 5;  // Was 4
    static constexpr int16_t PADDLE_HEIGHT = 30; // Was 25
    static constexpr int16_t BALL_DIAMETER = 5;  // Was 4

private:
    void resetBall(bool player_will_serve); // Renamed parameter for clarity

    GameState _current_state;
    int _player_score;
    int _ai_score;

    uint32_t _serve_delay_start_time; // When the serve delay began
    bool _player_serves_next;       // True if player serves after delay, false if AI

    int16_t _play_area_width;
    int16_t _play_area_height;

    Coordinates _player_paddle_coords;
    int16_t _player_paddle_velocity_y; // Current speed and direction of player paddle

    Coordinates _ai_paddle_coords;
    // AI paddle movement will be calculated in update()

    Coordinates _ball_coords;
    Coordinates _ball_velocity; // x and y components of ball's velocity

    // Speeds (pixels per update cycle, can be tuned)
    static constexpr int16_t INITIAL_PADDLE_SPEED = 3;
    static constexpr int16_t AI_PADDLE_SPEED = 1;          // AI moves slowly
    static constexpr int16_t AI_REACTION_THRESHOLD = 20; // Massively increased. AI reacts extremely late.
    static constexpr int16_t INITIAL_BALL_SPEED_X = 1;
    static constexpr int16_t INITIAL_BALL_SPEED_Y = 2;
    static constexpr uint32_t SERVE_DELAY_DURATION_MS = 1500; // 1.5 second delay before serve
};

#endif // PADDLE_GAME_H 

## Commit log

2025-03-10 Working demo of LVGL and ESP32-S3 RTFT
    [partitions.csv]
2025-03-11 Corrected buttons, multiline label
    [main.cpp]
2025-03-13 Let's ignore the unit testing JSON samples until such time as I can get sanitized/bogus variants
2025-03-13 Restore card behavior, need to fix buttons
    [main.cpp]
2025-03-13 Extract button handling and configuration to an Input class
2025-03-13 Card stack back on track
2025-03-13 VERTICAL SLICE COMPLETE YARGGHHHHHHHHHHHHH
    [partitions.csv]
2025-03-29 Working funnel chart, but crashy
    [InsightCard.cpp, InsightCard.h]
2025-03-29 Still not the right solution to the crashes
    [main.cpp]
2025-03-29 Clean up from that thrash which didn't solve anything
    [InsightCard.cpp, InsightCard.h, main.cpp]
2025-04-01 Rework requests to rely on a serial queue and system state
    [InsightCard.cpp, InsightCard.h, PostHogClient.cpp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]
2025-04-02 Correctly thread UI updates!
    [InsightCard.cpp, InsightCard.h]
2025-04-02 Kill the sample metrics card
2025-04-02 Use PSRAM to parse JSON, fix button and nav stack behavior
    [DisplayInterface.cpp, main.cpp]
2025-04-10 Display insight titles (for delete buttons) in the configuration UI
2025-04-10 Poor device's lemon buttons
2025-04-16 Break tight coupling between components using event queue
    [CardController.cpp, WifiInterface.cpp]
2025-04-17 Copy JSON into the UI task/thread and parse it there for safety
2025-04-17 De-slop the display interface
    [DisplayInterface.cpp]
2025-04-17 More reliably display funnels, prevent crashes
    [InsightCard.cpp, InsightCard.h, main.cpp]
2025-04-23 Add 3D printing and CAD files
    [Bezel assembly.step, DeskHog-all_parts.3mf, Enclosure*.step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]
2025-04-23 Update README.md with 3D printing link
2025-05-06 Basics of OTA updates
    [partitions.csv]
2025-05-08 OTA loading working, but flashing crashing
    [CaptivePortal.cpp, OtaManager.cpp, main.cpp]
2025-05-09 IT WORKSSSSSSS
    [partitions.csv]
2025-05-09 Fix config portal after refactor
    [CaptivePortal.cpp]
2025-05-09 Get the LED working again
2025-05-09 Fix for reactively loading new cards
    [CardController.cpp, InsightCard.cpp, InsightCard.h]
2025-05-11 Use the community-maintained esp/arduino project for PIO
2025-05-14 colours work, scroll doesn't
    [CardController.cpp]
2025-05-15 Revert "now with dynamic difficulty"
    This reverts commit c57e5ee4465385ea11b9be4749a0cf461ce7326b.
    [flappy_bird.cpp, flappy_bird.h]
2025-06-04 Fix path to pin definition
2025-06-05 Let’s use the center button
2025-06-10 “FriendCard”
2025-06-16 Change UK esp32-s3 supplier link
2025-06-17 add region buttons
2025-06-20 Whoops, missed a commit
    [CardController.cpp]
2025-06-20 Convert region radio buttons to dropdown UI
    - Replaced radio buttons with a select dropdown matching existing UI patterns
    - Removed unnecessary CSS styles for radio buttons
    - Updated html_portal.h with regenerated content
    - JavaScript already supports both radio buttons and dropdown (no changes needed)
2025-06-20 Fix for broken card stack after adding an insight
    [CardController.cpp, InsightCard.cpp]
2025-06-20 Center button forces refresh of insight
2025-06-25 Prevent ghost state cards
    [CardController.cpp]
2025-07-07 Power saving mechanisms
